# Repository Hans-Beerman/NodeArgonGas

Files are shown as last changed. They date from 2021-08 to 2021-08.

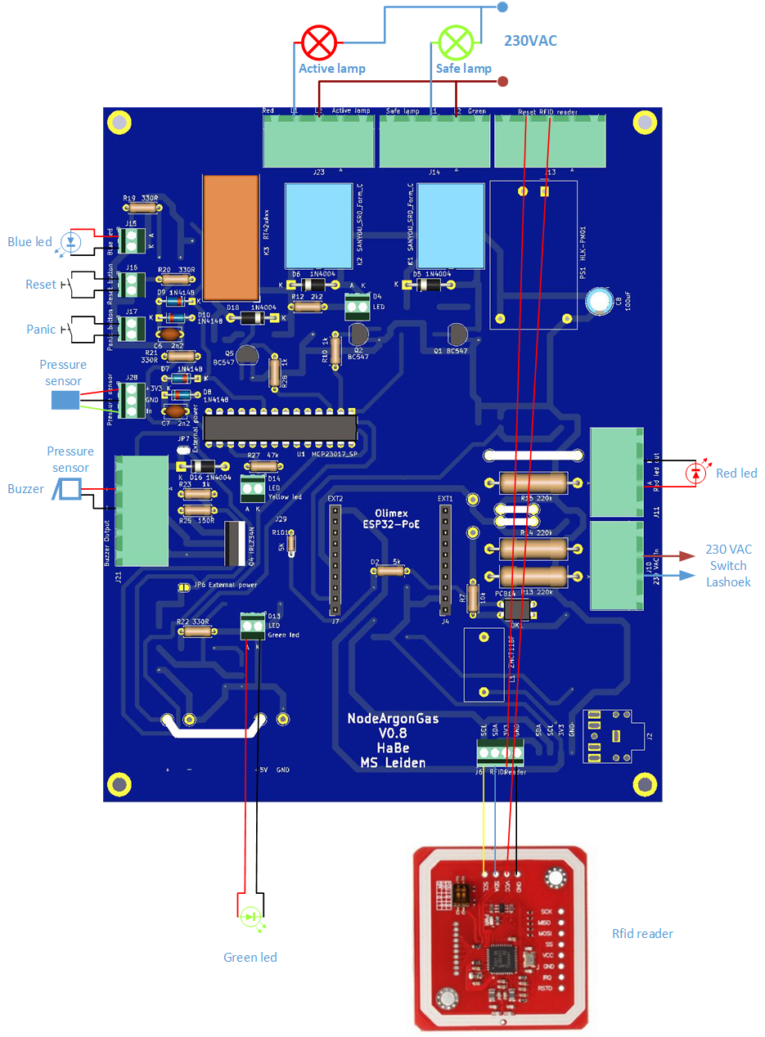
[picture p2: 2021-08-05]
Drawings/Aansluitschema PCB V0.1 20210801.png

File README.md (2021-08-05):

**NodeArgonGas**

NodeArgonGas is a node, used at the MakerSpace Leiden, to verify the state of the Argon Gas bottle, used for welding at the MakerSpace.

See for more information about this node:

[https://wiki.makerspaceleiden.nl/mediawiki/index.php/Project\_Monitoring\_Gasflessen](https://wiki.makerspaceleiden.nl/mediawiki/index.php/Project_Monitoring_Gasflessen)

This repository has the following subdirs:

**Drawings:**

- A schematic drawing, showing the wiring between the PCB used for this node and the external components, like push buttons, the pressure sensor, the RFid reader etc. (in MS Visio, png and pdf format);
- A \*.jpg picture of the PCB;
- Specification of the box in which the PCB and the other components are installed;
- A state diagram of software for this node (in MS Visio and pdf format).

**KiCad\_files:**

The design of the PCB used for the Node/Controller. For this node the NodeStandard PCB V0.8 is used. With less and other components than described for the NodeStandard. The changes are given in the MS Excel file in the root of this directory. There are also 2 subdirectories:

- _NodeArgonGas:_ This directory contains the schematic drawing for the NodeArgonGas and the PCB as used for this node. The design of the PCB in this directory is only made to show how the components for the node are placed on the NodeStandard PCB.
- _NodeStandard:_ This directory contains the design of the NodeStandard V0.8.

**Photos:**

Some photos of the Node made.

**PlatformIO\_Files:**

The source code for the Node. For the development of this software PlatformIO is used, an Extension on Visual Studio Code.

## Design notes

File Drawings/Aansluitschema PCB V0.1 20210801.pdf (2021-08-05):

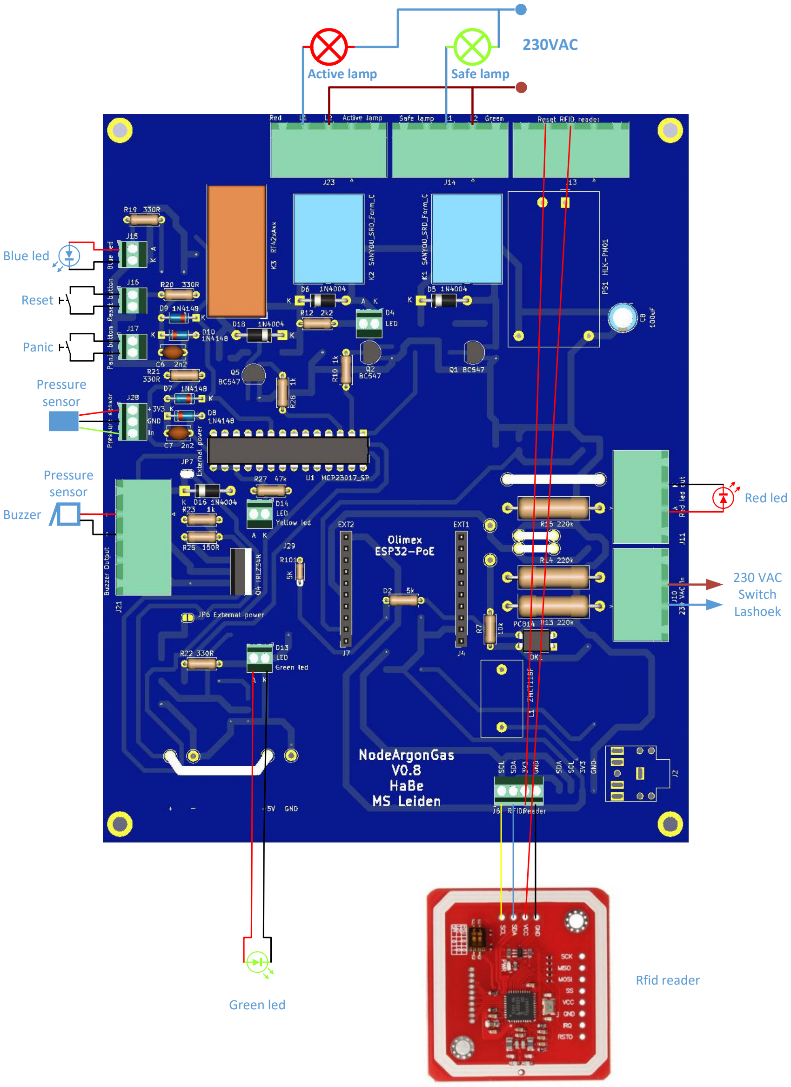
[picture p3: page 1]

Active lamp | Safe lamp

### 230VAC

Blue led

Reset

Panic

Buzzer

Pressure
sensor

Red led

Pressure
sensor

230 VAC
Switch
Lashoek

Rfid reader
Green led

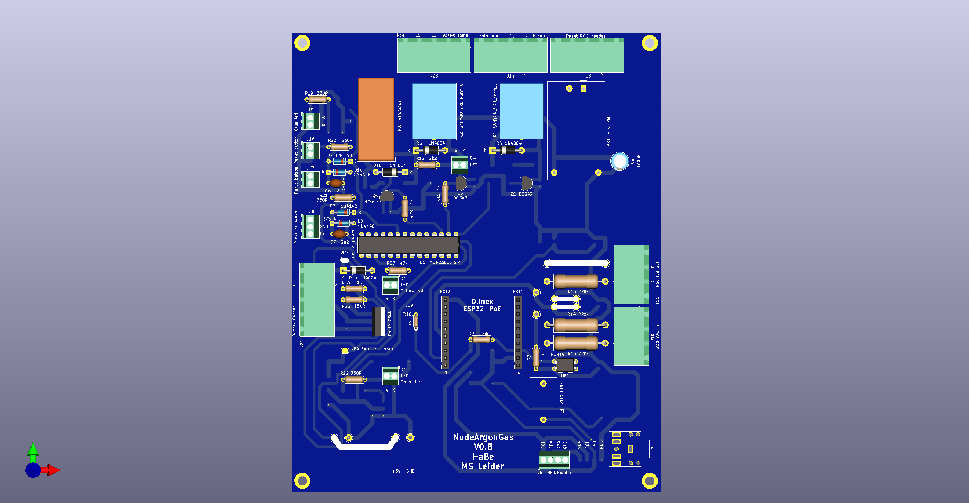
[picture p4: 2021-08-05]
KiCad_files/NodeArgonGas/NodeArgonGas.png

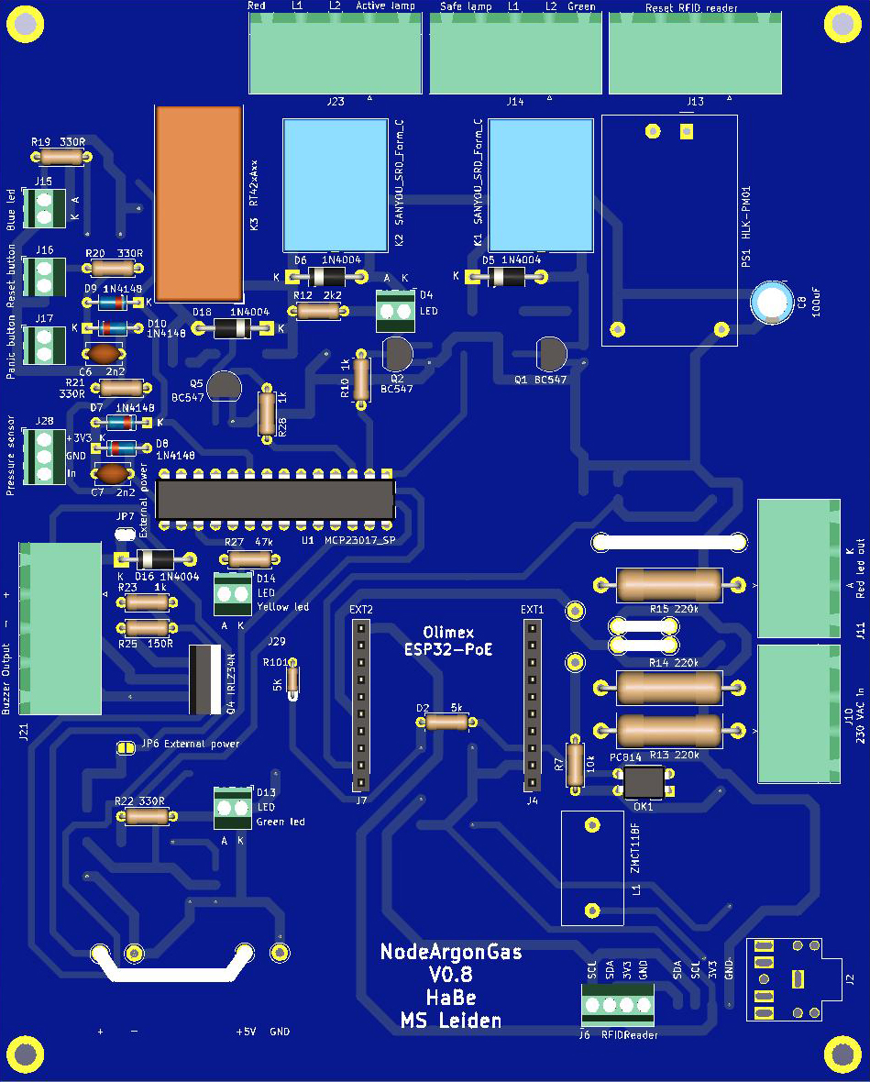
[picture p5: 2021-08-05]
Drawings/NodeArgonGas.jpg

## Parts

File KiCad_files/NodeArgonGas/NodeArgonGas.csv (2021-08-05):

Source: | /root/Projects/NodeArgonGas/KiCad_files/NodeArgonGas/NodeArgonGas.sch
Date: | ma 02 aug 2021 12:42:35 CEST
Tool: | Eeschema 5.1.10-88a1d61d58~90~ubuntu20.04.1
Generator: | /usr/share/kicad/plugins/bom_csv_grouped_by_value.py
Component Count: | 65
Individual Components:
Item | Qty | Reference(s) | Value | LibPart | Footprint | Datasheet | Field4 | Field5
 |  | C6 | 2n2 | Device:C | Capacitor_THT:C_Disc_D5.1mm_W3.2mm_P5.00mm | ~
 |  | C7 | 2n2 | Device:C | Capacitor_THT:C_Disc_D5.1mm_W3.2mm_P5.00mm | ~
 |  | C8 | 100uF | Device:CP | Capacitor_THT:CP_Radial_D6.3mm_P2.50mm | ~
 |  | D2 | 5k | Device:R | Resistor_THT:R_Axial_DIN0207_L6.3mm_D2.5mm_P7.62mm_Horizontal | ~
 |  | D4 | Led | Connector:Screw_Terminal_01x02 | Connector_Phoenix_MSTB:PhoenixContact_MSTB_2,5_2-GF-5,08_1x02_P5.08mm_Horizontal_ThreadedFlange | ~
 |  | D5 | 1N4004 | Diode:1N4004 | Diode_THT:D_DO-41_SOD81_P10.16mm_Horizontal | http://www.vishay.com/docs/88503/1n4001.pdf
 |  | D6 | 1N4004 | Diode:1N4004 | Diode_THT:D_DO-41_SOD81_P10.16mm_Horizontal | http://www.vishay.com/docs/88503/1n4001.pdf
 |  | D7 | 1N4148 | Diode:1N4148 | Diode_THT:D_DO-35_SOD27_P7.62mm_Horizontal | https://assets.nexperia.com/documents/data-sheet/1N4148_1N4448.pdf
 |  | D8 | 1N4148 | Diode:1N4148 | Diode_THT:D_DO-35_SOD27_P7.62mm_Horizontal | https://assets.nexperia.com/documents/data-sheet/1N4148_1N4448.pdf
 |  | D9 | 1N4148 | Diode:1N4148 | Diode_THT:D_DO-35_SOD27_P7.62mm_Horizontal | https://assets.nexperia.com/documents/data-sheet/1N4148_1N4448.pdf
 |  | D10 | 1N4148 | Diode:1N4148 | Diode_THT:D_DO-35_SOD27_P7.62mm_Horizontal | https://assets.nexperia.com/documents/data-sheet/1N4148_1N4448.pdf
 |  | D13 | Green led | Connector:Screw_Terminal_01x02 | Connector_Phoenix_MSTB:PhoenixContact_MSTB_2,5_2-GF-5,08_1x02_P5.08mm_Horizontal_ThreadedFlange | ~
 |  | D14 | Yellow led | Connector:Screw_Terminal_01x02 | Connector_Phoenix_MSTB:PhoenixContact_MSTB_2,5_2-GF-5,08_1x02_P5.08mm_Horizontal_ThreadedFlange | ~
 |  | D16 | 1N4004 | Diode:1N4004 | Diode_THT:D_DO-41_SOD81_P10.16mm_Horizontal | http://www.vishay.com/docs/88503/1n4001.pdf
 |  | D18 | 1N4004 | Diode:1N4004 | Diode_THT:D_DO-41_SOD81_P10.16mm_Horizontal | http://www.vishay.com/docs/88503/1n4001.pdf
 |  | J4 | EXT1 | Connector_Generic:Conn_01x10 | Connector_PinSocket_2.54mm:PinSocket_1x10_P2.54mm_Vertical | ~
 |  | J6 | RFIDReader | Connector:Screw_Terminal_01x04 | TerminalBlock_Phoenix:TerminalBlock_Phoenix_MPT-0,5-4-2.54_1x04_P2.54mm_Horizontal | ~
 |  | J7 | EXT2 | Connector_Generic:Conn_01x10 | Connector_PinSocket_2.54mm:PinSocket_1x10_P2.54mm_Vertical | ~
 |  | J10 | Opto Coupler 1 in | Connector:Screw_Terminal_01x02 | Connector_Phoenix_MSTB:PhoenixContact_MSTB_2,5_2-GF-5,08_1x02_P5.08mm_Horizontal_ThreadedFlange | ~
 |  | J11 | Red led output | Connector:Screw_Terminal_01x02 | Connector_Phoenix_MSTB:PhoenixContact_MSTB_2,5_2-GF-5,08_1x02_P5.08mm_Horizontal_ThreadedFlange | ~
 |  | J13 | Reset RFid reader | Connector:Screw_Terminal_01x03 | Connector_Phoenix_MSTB:PhoenixContact_MSTB_2,5_3-GF-5,08_1x03_P5.08mm_Horizontal_ThreadedFlange | ~
 |  | J14 | Safe lamp (Output) | Connector:Screw_Terminal_01x03 | Connector_Phoenix_MSTB:PhoenixContact_MSTB_2,5_3-GF-5,08_1x03_P5.08mm_Horizontal_ThreadedFlange | ~
 |  | J15 | Blue led out | Connector:Screw_Terminal_01x02 | TerminalBlock_Phoenix:TerminalBlock_Phoenix_MPT-0,5-2-2.54_1x02_P2.54mm_Horizontal | ~
 |  | J16 | Panic button in | Connector:Screw_Terminal_01x02 | TerminalBlock_Phoenix:TerminalBlock_Phoenix_MPT-0,5-2-2.54_1x02_P2.54mm_Horizontal | ~
 |  | J17 | Reset button in | Connector:Screw_Terminal_01x02 | TerminalBlock_Phoenix:TerminalBlock_Phoenix_MPT-0,5-2-2.54_1x02_P2.54mm_Horizontal | ~
 |  | J21 | Buzzer output | Connector:Screw_Terminal_01x03 | Connector_Phoenix_MSTB:PhoenixContact_MSTB_2,5_3-GF-5,08_1x03_P5.08mm_Horizontal_ThreadedFlange | ~
 |  | J23 | Active lamp (output) | Connector:Screw_Terminal_01x03 | Connector_Phoenix_MSTB:PhoenixContact_MSTB_2,5_3-GF-5,08_1x03_P5.08mm_Horizontal_ThreadedFlange | ~
 |  | J24 | Relay 3 Output 2 (not installed) | Connector:Screw_Terminal_01x03 | Connector_Phoenix_MSTB:PhoenixContact_MSTB_2,5_3-GF-5,08_1x03_P5.08mm_Horizontal_ThreadedFlange | ~
 |  | J25 | 230VAC in | Connector:Screw_Terminal_01x02 | Connector_Phoenix_MSTB:PhoenixContact_MSTB_2,5_2-GF-5,08_1x02_P5.08mm_Horizontal_ThreadedFlange | ~
 |  | J26 | 5V-in | Connector:Screw_Terminal_01x02 | Connector_Phoenix_MSTB:PhoenixContact_MSTB_2,5_2-GF-5,08_1x02_P5.08mm_Horizontal_ThreadedFlange | ~
 |  | J27 | ExtDC-in | Connector:Screw_Terminal_01x02 | Connector_Phoenix_MSTB:PhoenixContact_MSTB_2,5_2-GF-5,08_1x02_P5.08mm_Horizontal_ThreadedFlange | ~
 |  | J28 | Pressure sensor | Connector:Screw_Terminal_01x03 | TerminalBlock_Phoenix:TerminalBlock_Phoenix_MPT-0,5-3-2.54_1x03_P2.54mm_Horizontal | ~
 |  | J29 | J29 is replaced by R101 | Connector_Generic:Conn_01x03 | Connector_PinHeader_2.54mm:PinHeader_1x03_P2.54mm_Vertical | ~
 |  | JP1 | 230VAC-N | Jumper:SolderJumper_2_Open | Footprints:SolderJumper-2_P3mm_Open_RoundedPad | ~
 |  | JP4 | 230VAC-L | Jumper:SolderJumper_2_Open | Footprints:SolderJumper-2_P3mm_Open_RoundedPad | ~
 |  | JP5 | 230VAC-L | Jumper:SolderJumper_2_Open | Footprints:SolderJumper-2_P3mm_Open_RoundedPad | ~
 |  | JP7 | External power | Jumper:SolderJumper_2_Open | Jumper:SolderJumper-2_P1.3mm_Open_RoundedPad1.0x1.5mm | ~
 |  | JP8 | 230VAC-L | Jumper:SolderJumper_2_Open | Footprints:SolderJumper-2_P3mm_Open_RoundedPad | ~
 |  | K1 | SANYOU_SRD_Form_C | Relay:SANYOU_SRD_Form_C | Relay_THT:Relay_SPDT_SANYOU_SRD_Series_Form_C | http://www.sanyourelay.ca/public/products/pdf/SRD.pdf
 |  | K2 | SANYOU_SRD_Form_C | Relay:SANYOU_SRD_Form_C | Relay_THT:Relay_SPDT_SANYOU_SRD_Series_Form_C | http://www.sanyourelay.ca/public/products/pdf/SRD.pdf
 |  | K3 | RT42xAxx | Relay:RT42xAxx | Relay_THT:Relay_DPDT_Schrack-RT2-FormC_RM5mm | http://www.te.com/commerce/DocumentDelivery/DDEController?Action=showdoc
 |  | OK1 | PC814 | PC814:PC814 | Package_DIP:DIP-4_W7.62mm |  | unknown | 9707662
 |  | PS1 | HLK-PM01 | Converter_ACDC:HLK-PM01 | Converter_ACDC:Converter_ACDC_HiLink_HLK-PMxx | http://www.hlktech.net/product_detail.php?ProId=54
 |  | Q1 | BC547 | Transistor_BJT:BC547 | Package_TO_SOT_THT:TO-92_Inline | http://www.fairchildsemi.com/ds/BC/BC547.pdf
 |  | Q2 | BC547 | Transistor_BJT:BC547 | Package_TO_SOT_THT:TO-92_Inline | http://www.fairchildsemi.com/ds/BC/BC547.pdf
 |  | Q4 | IRLZ34N | Transistor_FET:IRLZ34N | Package_TO_SOT_THT:TO-220-3_Vertical | http://www.infineon.com/dgdl/irlz34npbf.pdf?fileId=5546d462533600a40153567206892720
 |  | Q5 | BC547 | Transistor_BJT:BC547 | Package_TO_SOT_THT:TO-92_Inline | http://www.fairchildsemi.com/ds/BC/BC547.pdf
 |  | R7 | 10k | Device:R | Resistor_THT:R_Axial_DIN0207_L6.3mm_D2.5mm_P7.62mm_Horizontal | ~
 |  | R9 | 1k | Device:R | Resistor_THT:R_Axial_DIN0207_L6.3mm_D2.5mm_P7.62mm_Horizontal | ~
 |  | R10 | 1k | Device:R | Resistor_THT:R_Axial_DIN0207_L6.3mm_D2.5mm_P7.62mm_Horizontal | ~
 |  | R12 | 2k2 | Device:R | Resistor_THT:R_Axial_DIN0207_L6.3mm_D2.5mm_P7.62mm_Horizontal | ~
 |  | R13 | 220k | Device:R | Resistor_THT:R_Axial_DIN0516_L15.5mm_D5.0mm_P20.32mm_Horizontal | ~
 |  | R14 | 220k | Device:R | Resistor_THT:R_Axial_DIN0516_L15.5mm_D5.0mm_P20.32mm_Horizontal | ~
 |  | R15 | 330R | Device:R | Resistor_THT:R_Axial_DIN0516_L15.5mm_D5.0mm_P20.32mm_Horizontal | ~
 |  | R16 | 0R | Device:R | Resistor_THT:R_Axial_DIN0516_L15.5mm_D5.0mm_P20.32mm_Horizontal | ~
 |  | R19 | 330R | Device:R | Resistor_THT:R_Axial_DIN0207_L6.3mm_D2.5mm_P7.62mm_Horizontal | ~
 |  | R20 | 330R | Device:R | Resistor_THT:R_Axial_DIN0207_L6.3mm_D2.5mm_P7.62mm_Horizontal | ~
 |  | R21 | 330R | Device:R | Resistor_THT:R_Axial_DIN0207_L6.3mm_D2.5mm_P7.62mm_Horizontal | ~
 |  | R22 | 330R | Device:R | Resistor_THT:R_Axial_DIN0207_L6.3mm_D2.5mm_P7.62mm_Horizontal | ~
 |  | R23 | 1k | Device:R | Resistor_THT:R_Axial_DIN0207_L6.3mm_D2.5mm_P7.62mm_Horizontal | ~
 |  | R25 | 150R | Device:R | Resistor_THT:R_Axial_DIN0207_L6.3mm_D2.5mm_P7.62mm_Horizontal | ~
 |  | R27 | 47k | Device:R | Resistor_THT:R_Axial_DIN0207_L6.3mm_D2.5mm_P7.62mm_Horizontal | ~
 |  | R28 | 1k | Device:R | Resistor_THT:R_Axial_DIN0207_L6.3mm_D2.5mm_P7.62mm_Horizontal | ~
 |  | R101 | 5k | Device:R | Resistor_THT:R_Axial_DIN0207_L6.3mm_D2.5mm_P7.62mm_Horizontal | ~
 |  | U1 | MCP23017_SP | Interface_Expansion:MCP23017_SP | Package_DIP:DIP-28_W7.62mm | http://ww1.microchip.com/downloads/en/DeviceDoc/20001952C.pdf
Collated Components:
Item | Qty | Reference(s) | Value | LibPart | Footprint | Datasheet | Field4 | Field5
1 | 2 | C6, C7 | 2n2 | Device:C | Capacitor_THT:C_Disc_D5.1mm_W3.2mm_P5.00mm | ~
2 | 1 | C8 | 100uF | Device:CP | Capacitor_THT:CP_Radial_D6.3mm_P2.50mm | ~
3 | 2 | D2, R101 | 5k | Device:R | Resistor_THT:R_Axial_DIN0207_L6.3mm_D2.5mm_P7.62mm_Horizontal | ~
4 | 1 | D4 | Led | Connector:Screw_Terminal_01x02 | Connector_Phoenix_MSTB:PhoenixContact_MSTB_2,5_2-GF-5,08_1x02_P5.08mm_Horizontal_ThreadedFlange | ~
5 | 4 | D5, D6, D16, D18 | 1N4004 | Diode:1N4004 | Diode_THT:D_DO-41_SOD81_P10.16mm_Horizontal | http://www.vishay.com/docs/88503/1n4001.pdf
6 | 4 | D7, D8, D9, D10 | 1N4148 | Diode:1N4148 | Diode_THT:D_DO-35_SOD27_P7.62mm_Horizontal | https://assets.nexperia.com/documents/data-sheet/1N4148_1N4448.pdf
7 | 1 | D13 | Green led | Connector:Screw_Terminal_01x02 | Connector_Phoenix_MSTB:PhoenixContact_MSTB_2,5_2-GF-5,08_1x02_P5.08mm_Horizontal_ThreadedFlange | ~
8 | 1 | D14 | Yellow led | Connector:Screw_Terminal_01x02 | Connector_Phoenix_MSTB:PhoenixContact_MSTB_2,5_2-GF-5,08_1x02_P5.08mm_Horizontal_ThreadedFlange | ~
9 | 1 | J4 | EXT1 | Connector_Generic:Conn_01x10 | Connector_PinSocket_2.54mm:PinSocket_1x10_P2.54mm_Vertical | ~
10 | 1 | J6 | RFIDReader | Connector:Screw_Terminal_01x04 | TerminalBlock_Phoenix:TerminalBlock_Phoenix_MPT-0,5-4-2.54_1x04_P2.54mm_Horizontal | ~
11 | 1 | J7 | EXT2 | Connector_Generic:Conn_01x10 | Connector_PinSocket_2.54mm:PinSocket_1x10_P2.54mm_Vertical | ~
12 | 1 | J10 | Opto Coupler 1 in | Connector:Screw_Terminal_01x02 | Connector_Phoenix_MSTB:PhoenixContact_MSTB_2,5_2-GF-5,08_1x02_P5.08mm_Horizontal_ThreadedFlange | ~
13 | 1 | J11 | Red led output | Connector:Screw_Terminal_01x02 | Connector_Phoenix_MSTB:PhoenixContact_MSTB_2,5_2-GF-5,08_1x02_P5.08mm_Horizontal_ThreadedFlange | ~
14 | 1 | J13 | Reset RFid reader | Connector:Screw_Terminal_01x03 | Connector_Phoenix_MSTB:PhoenixContact_MSTB_2,5_3-GF-5,08_1x03_P5.08mm_Horizontal_ThreadedFlange | ~
15 | 1 | J14 | Safe lamp (Output) | Connector:Screw_Terminal_01x03 | Connector_Phoenix_MSTB:PhoenixContact_MSTB_2,5_3-GF-5,08_1x03_P5.08mm_Horizontal_ThreadedFlange | ~
16 | 1 | J15 | Blue led out | Connector:Screw_Terminal_01x02 | TerminalBlock_Phoenix:TerminalBlock_Phoenix_MPT-0,5-2-2.54_1x02_P2.54mm_Horizontal | ~
17 | 1 | J16 | Panic button in | Connector:Screw_Terminal_01x02 | TerminalBlock_Phoenix:TerminalBlock_Phoenix_MPT-0,5-2-2.54_1x02_P2.54mm_Horizontal | ~
18 | 1 | J17 | Reset button in | Connector:Screw_Terminal_01x02 | TerminalBlock_Phoenix:TerminalBlock_Phoenix_MPT-0,5-2-2.54_1x02_P2.54mm_Horizontal | ~
19 | 1 | J21 | Buzzer output | Connector:Screw_Terminal_01x03 | Connector_Phoenix_MSTB:PhoenixContact_MSTB_2,5_3-GF-5,08_1x03_P5.08mm_Horizontal_ThreadedFlange | ~
20 | 1 | J23 | Active lamp (output) | Connector:Screw_Terminal_01x03 | Connector_Phoenix_MSTB:PhoenixContact_MSTB_2,5_3-GF-5,08_1x03_P5.08mm_Horizontal_ThreadedFlange | ~
21 | 1 | J24 | Relay 3 Output 2 (not installed) | Connector:Screw_Terminal_01x03 | Connector_Phoenix_MSTB:PhoenixContact_MSTB_2,5_3-GF-5,08_1x03_P5.08mm_Horizontal_ThreadedFlange | ~
22 | 1 | J25 | 230VAC in | Connector:Screw_Terminal_01x02 | Connector_Phoenix_MSTB:PhoenixContact_MSTB_2,5_2-GF-5,08_1x02_P5.08mm_Horizontal_ThreadedFlange | ~
23 | 1 | J26 | 5V-in | Connector:Screw_Terminal_01x02 | Connector_Phoenix_MSTB:PhoenixContact_MSTB_2,5_2-GF-5,08_1x02_P5.08mm_Horizontal_ThreadedFlange | ~
24 | 1 | J27 | ExtDC-in | Connector:Screw_Terminal_01x02 | Connector_Phoenix_MSTB:PhoenixContact_MSTB_2,5_2-GF-5,08_1x02_P5.08mm_Horizontal_ThreadedFlange | ~
25 | 1 | J28 | Pressure sensor | Connector:Screw_Terminal_01x03 | TerminalBlock_Phoenix:TerminalBlock_Phoenix_MPT-0,5-3-2.54_1x03_P2.54mm_Horizontal | ~
26 | 1 | J29 | J29 is replaced by R101 | Connector_Generic:Conn_01x03 | Connector_PinHeader_2.54mm:PinHeader_1x03_P2.54mm_Vertical | ~
27 | 1 | JP1 | 230VAC-N | Jumper:SolderJumper_2_Open | Footprints:SolderJumper-2_P3mm_Open_RoundedPad | ~
28 | 3 | JP4, JP5, JP8 | 230VAC-L | Jumper:SolderJumper_2_Open | Footprints:SolderJumper-2_P3mm_Open_RoundedPad | ~
29 | 1 | JP7 | External power | Jumper:SolderJumper_2_Open | Jumper:SolderJumper-2_P1.3mm_Open_RoundedPad1.0x1.5mm | ~
30 | 2 | K1, K2 | SANYOU_SRD_Form_C | Relay:SANYOU_SRD_Form_C | Relay_THT:Relay_SPDT_SANYOU_SRD_Series_Form_C | http://www.sanyourelay.ca/public/products/pdf/SRD.pdf
31 | 1 | K3 | RT42xAxx | Relay:RT42xAxx | Relay_THT:Relay_DPDT_Schrack-RT2-FormC_RM5mm | http://www.te.com/commerce/DocumentDelivery/DDEController?Action=showdoc
32 | 1 | OK1 | PC814 | PC814:PC814 | Package_DIP:DIP-4_W7.62mm |  | unknown | 9707662
33 | 1 | PS1 | HLK-PM01 | Converter_ACDC:HLK-PM01 | Converter_ACDC:Converter_ACDC_HiLink_HLK-PMxx | http://www.hlktech.net/product_detail.php?ProId=54
34 | 3 | Q1, Q2, Q5 | BC547 | Transistor_BJT:BC547 | Package_TO_SOT_THT:TO-92_Inline | http://www.fairchildsemi.com/ds/BC/BC547.pdf
35 | 1 | Q4 | IRLZ34N | Transistor_FET:IRLZ34N | Package_TO_SOT_THT:TO-220-3_Vertical | http://www.infineon.com/dgdl/irlz34npbf.pdf?fileId=5546d462533600a40153567206892720
36 | 1 | R7 | 10k | Device:R | Resistor_THT:R_Axial_DIN0207_L6.3mm_D2.5mm_P7.62mm_Horizontal | ~
37 | 4 | R9, R10, R23, R28 | 1k | Device:R | Resistor_THT:R_Axial_DIN0207_L6.3mm_D2.5mm_P7.62mm_Horizontal | ~
38 | 1 | R12 | 2k2 | Device:R | Resistor_THT:R_Axial_DIN0207_L6.3mm_D2.5mm_P7.62mm_Horizontal | ~
39 | 2 | R13, R14 | 220k | Device:R | Resistor_THT:R_Axial_DIN0516_L15.5mm_D5.0mm_P20.32mm_Horizontal | ~
40 | 1 | R15 | 330R | Device:R | Resistor_THT:R_Axial_DIN0516_L15.5mm_D5.0mm_P20.32mm_Horizontal | ~
41 | 1 | R16 | 0R | Device:R | Resistor_THT:R_Axial_DIN0516_L15.5mm_D5.0mm_P20.32mm_Horizontal | ~
42 | 4 | R19, R20, R21, R22 | 330R | Device:R | Resistor_THT:R_Axial_DIN0207_L6.3mm_D2.5mm_P7.62mm_Horizontal | ~
43 | 1 | R25 | 150R | Device:R | Resistor_THT:R_Axial_DIN0207_L6.3mm_D2.5mm_P7.62mm_Horizontal | ~
44 | 1 | R27 | 47k | Device:R | Resistor_THT:R_Axial_DIN0207_L6.3mm_D2.5mm_P7.62mm_Horizontal | ~
45 | 1 | U1 | MCP23017_SP | Interface_Expansion:MCP23017_SP | Package_DIP:DIP-28_W7.62mm | http://ww1.microchip.com/downloads/en/DeviceDoc/20001952C.pdf

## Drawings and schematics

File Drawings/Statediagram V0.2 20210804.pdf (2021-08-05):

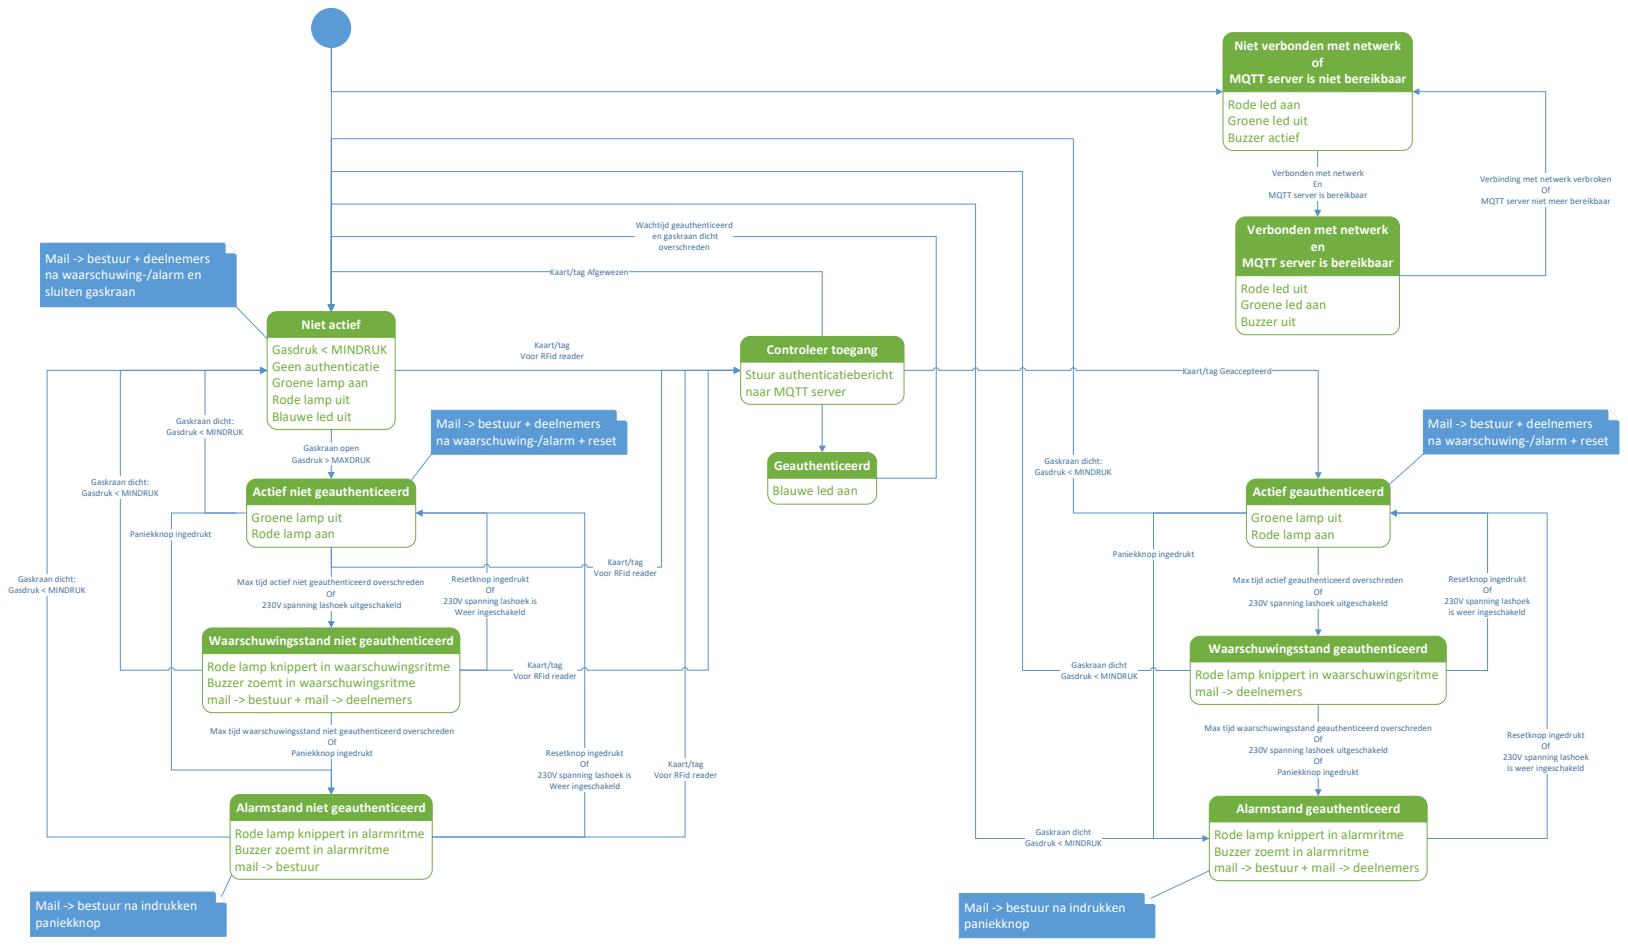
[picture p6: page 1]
Kaart/tag; Voor RFid reader; Controleer toegang; Of Paniekknop ingedrukt; Gaskraan dicht Gasdruk < MINDRUK; Gaskraan dicht: Gasdruk < MINDRUK; Resetknop ingedrukt Of; Paniekknop ingedrukt

Niet verbonden met netwerk

MQTT server is niet bereikbaar
Rode led aan
Groene led uit
Buzzer actief

Verbonden met netwerk MQTT server is bereikbaar | En

Verbinding met netwerk verbroken MQTT server niet meer bereikbaar | Of

Wachtijd geauthenticeerd
en gaskraan dicht
overschreden

Verbonden met netwerk

Mail -> bestuur + deelnemers
na waarschuwing-/alarm en
sluiten gaskraan

MQTT server is bereikbaar
Rode led uit
Groene led aan
Buzzer uit

Kaart/tag Afgewezen

Niet actief
Gasdruk < MINDRUK
Geen authenticatie
Groene lamp aan
Rode lamp uit
Blauwe led uit

Stuur authenticatiebericht
naar MQTT server

Kaart/tag Geaccepteerd

Gaskraan dicht: Gasdruk < MINDRUK

na waarschuwing-/alarm + reset

Gaskraan open Gasdruk > MAXDRUK

Geauthenticeerd
Blauwe led aan

Actief niet geauthenticeerd
Groene lamp uit
Rode lamp aan

Actief geauthenticeerd

Kaart/tag
Voor RFid reader

Max tijd actief niet geauthenticeerd overschreden

Max tijd actief geauthenticeerd overschreden

230V spanning lashoek uitgeschakeld

230V spanning lashoek is
Weer ingeschakeld

230V spanning lashoek
is weer ingeschakeld

Waarschuwingsstand niet geauthenticeerd
Rode lamp knippert in waarschuwingsritme
Buzzer zoemt in waarschuwingsritme
mail -> bestuur + mail -> deelnemers

Waarschuwingsstand geauthenticeerd
mail -> deelnemers

Max tijd waarschuwingsstand niet geauthenticeerd overschreden

Max tijd waarschuwingsstand geauthenticeerd overschreden

Is weer ingeschakeld

Alarmstand niet geauthenticeerd
Rode lamp knippert in alarmritme
Buzzer zoemt in alarmritme
mail -> bestuur

Alarmstand geauthenticeerd

Mail -> bestuur na indrukken
paniekknop

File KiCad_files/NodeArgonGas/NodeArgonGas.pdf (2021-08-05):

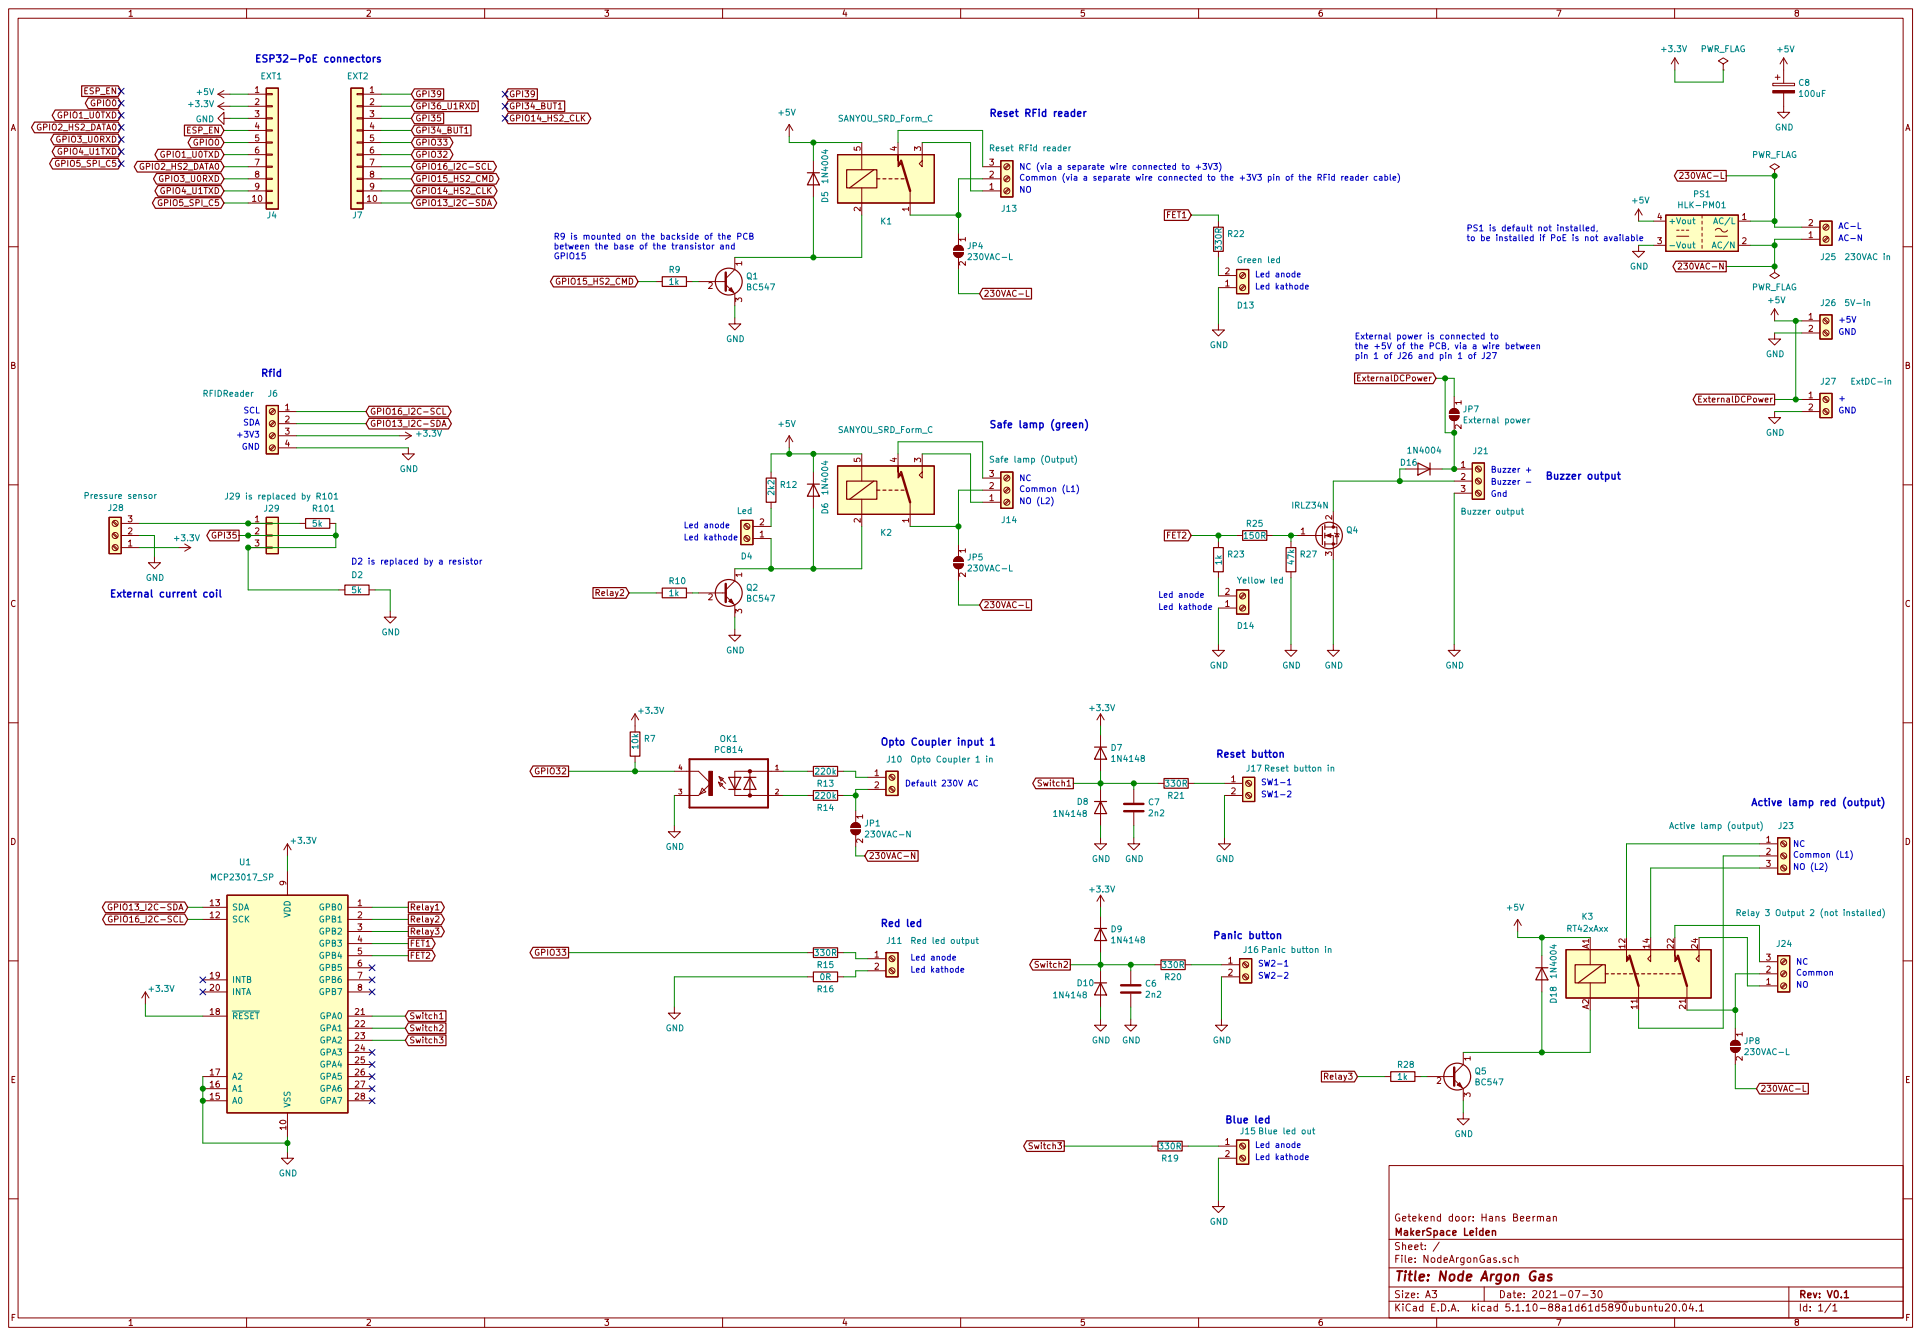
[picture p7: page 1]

pin 1 of J26 and pin 1 of J27 ESP32-PoE connectors

NC (via a separate wire connected to +3V3)
Common (via a separate wire connected to the +3V3 pin of the RFid reader cable)

to be installed if PoE is not available

External power is connected to
the +5V of the PCB, via a wire between

Led kathode D2 is replaced by a resistor

NC Active lamp red (output)

Panic button Blue led

J24 Relay 3 Output 2 (not installed)

File: NodeArgonGas.sch Sheet: / MakerSpace Leiden Getekend door: Hans Beerman

Id: 1/1 Title: Node Argon Gas

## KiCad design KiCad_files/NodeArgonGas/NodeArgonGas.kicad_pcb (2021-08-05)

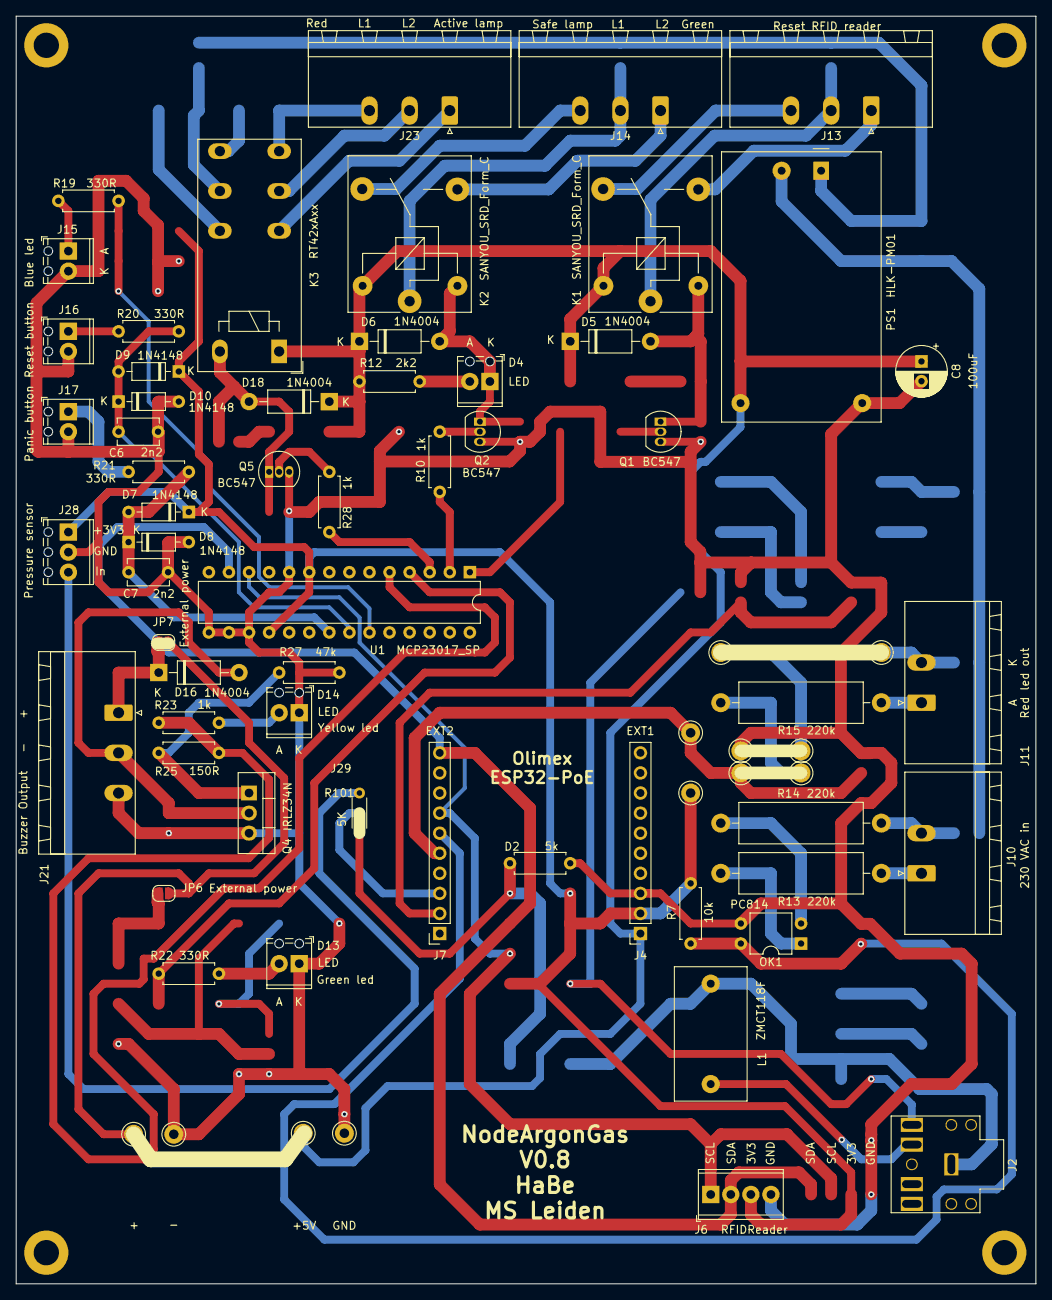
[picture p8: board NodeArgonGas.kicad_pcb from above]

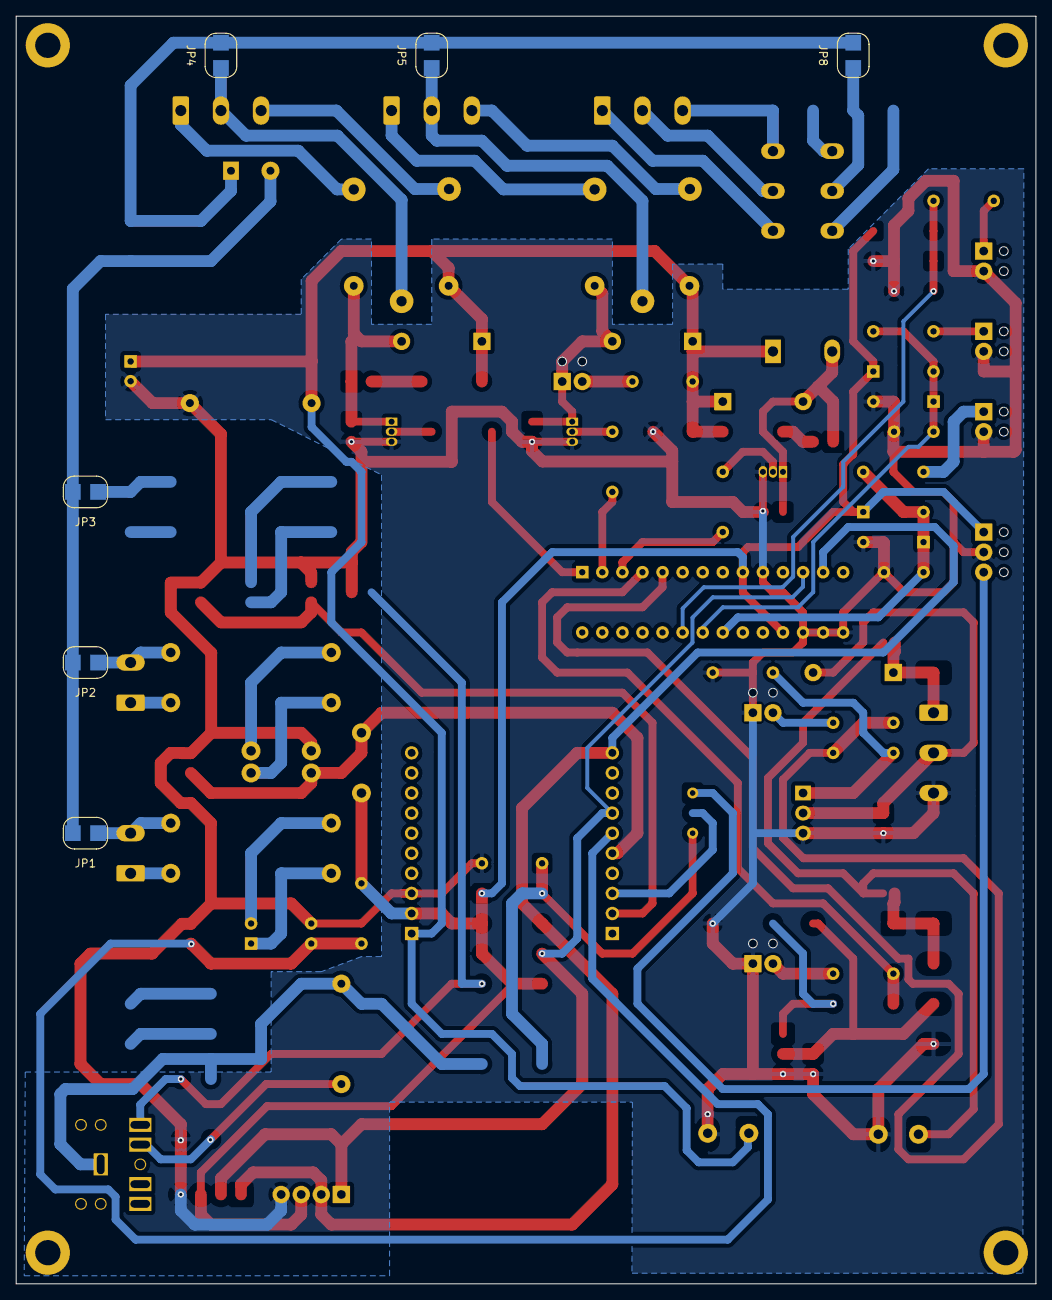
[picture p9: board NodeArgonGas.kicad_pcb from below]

Board: 2 copper layers, 129.0 x 160.4 mm, 63 parts (6 on the bottom side), 50 nets.

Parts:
C6, C7: 2n2; C_Disc_D5.1mm_W3.2mm_P5.00mm
C8: 100uF; CP_Radial_D6.3mm_P2.50mm
D2: 5k; R_Axial_DIN0207_L6.3mm_D2.5mm_P7.62mm_Horizontal
D4, D13, D14: LED; TerminalBlock_Phoenix_MPT-0,5-2-2.54_1x02_P2.54mm_Horizontal
D5, D6, D16, D18: 1N4004; D_DO-41_SOD81_P10.16mm_Horizontal
D7, D8, D9, D10: 1N4148; D_DO-35_SOD27_P7.62mm_Horizontal
J2: Current coil in; Jack_3.5mm_CUI_FEMPM_Horizontal
J4: EXT1; PinSocket_1x10_P2.54mm_Vertical
J6: RFIDReader; TerminalBlock_Phoenix_MPT-0,5-4-2.54_1x04_P2.54mm_Horizontal
J7: EXT2; PinSocket_1x10_P2.54mm_Vertical
J10: 230 VAC in; PhoenixContact_MSTB_2,5_2-GF-5,08_1x02_P5.08mm_Horizontal_T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
J11: Red led out; PhoenixContact_MSTB_2,5_2-GF-5,08_1x02_P5.08mm_Horizontal_T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
J13: Reset RFID reader; PhoenixContact_MSTB_2,5_3-GF-5,08_1x03_P5.08mm_Horizontal_T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
J14: Safe lamp L1 L2 Green; PhoenixContact_MSTB_2,5_3-GF-5,08_1x03_P5.08mm_Horizontal_T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
J15: Blue led; TerminalBlock_Phoenix_MPT-0,5-2-2.54_1x02_P2.54mm_Horizontal
J16: Reset button; TerminalBlock_Phoenix_MPT-0,5-2-2.54_1x02_P2.54mm_Horizontal
J17: Panic button; TerminalBlock_Phoenix_MPT-0,5-2-2.54_1x02_P2.54mm_Horizontal
J21: Buzzer Output - +; PhoenixContact_MSTB_2,5_3-GF-5,08_1x03_P5.08mm_Horizontal_T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
J23: Red L1 L2 Active lamp; PhoenixContact_MSTB_2,5_3-GF-5,08_1x03_P5.08mm_Horizontal_T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
J28: Pressure sensor; TerminalBlock_Phoenix_MPT-0,5-3-2.54_1x03_P2.54mm_Horizontal
J29: 5K; R_Axial_DIN0204_L3.6mm_D1.6mm_P5.08mm_Horizontal
JP1, JP2, JP3: 230VAC-N; SolderJumper-2_P3mm_Open_RoundedPad
JP4, JP5, JP8: 230VAC-L; SolderJumper-2_P3mm_Open_RoundedPad
JP6, JP7: External power; SolderJumper-2_P1.3mm_Open_RoundedPad1.0x1.5mm
K1, K2: SANYOU_SRD_Form_C; Relay_SPDT_SANYOU_SRD_Series_Form_C
K3: RT42xAxx; Relay_DPDT_Schrack-RT2-FormC_RM5mm
L1: ZMCT118F; TA12-100
OK1: PC814; DIP-4_W7.62mm
PS1: HLK-PM01; Converter_ACDC_HiLink_HLK-PMxx
Q1, Q2, Q5: BC547; TO-92_Inline
Q4: IRLZ34N; TO-220-3_Vertical
R7: 10k; R_Axial_DIN0207_L6.3mm_D2.5mm_P7.62mm_Horizontal
R10, R23, R28: 1k; R_Axial_DIN0207_L6.3mm_D2.5mm_P7.62mm_Horizontal
R12: 2k2; R_Axial_DIN0207_L6.3mm_D2.5mm_P7.62mm_Horizontal
R13, R14, R15: 220k; R_Axial_DIN0516_L15.5mm_D5.0mm_P20.32mm_Horizontal
R19, R20, R21, R22: 330R; R_Axial_DIN0207_L6.3mm_D2.5mm_P7.62mm_Horizontal
R25: 150R; R_Axial_DIN0207_L6.3mm_D2.5mm_P7.62mm_Horizontal
R27: 47k; R_Axial_DIN0207_L6.3mm_D2.5mm_P7.62mm_Horizontal
U1: MCP23017_SP; DIP-28_W7.62mm

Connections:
230VAC-L: JP4.2, JP5.2, JP8.2, PS1.1
230VAC-N: JP1.2, JP2.2, JP3.2, PS1.2
+3V3: D7.1, D9.1, J4.2, J6.3, J28.1, R7.1, U1.9, U1.18
+5V: C8.1, D5.1, D6.1, D18.1, J4.1, K1.5, K2.5, K3.A1, PS1.4, R12.1
ExternalDCPower: JP6.1, JP7.1
FET1: R22.1, U1.4
FET2: R23.1, R25.2, U1.5
GND: C6.2, C7.2, C8.2, D2.2, D8.2, D10.2, D13.1, D14.1, J4.3, J6.4, J15.2, J16.2, J17.2, J28.2, OK1.3, PS1.3, Q1.3, Q2.3, Q4.3, Q5.3, R27.2, U1.10, U1.15, U1.16, U1.17
GPI35: J7.3, J29.2
GPIO13_I2C-SDA: J6.2, J7.10, U1.13
GPIO16_I2C-SCL: J6.1, J7.7, U1.12
GPIO32: J7.6, OK1.4, R7.2
unnamed: D5.2, K1.2, Q1.1
unnamed: D4.1, D6.2, K2.2, Q2.1
unnamed: D4.2, R12.2
unnamed: D13.2, R22.2
unnamed: D14.2, R23.2
unnamed: D16.1, J21.1, J21.2, JP7.2
unnamed: D16.2, J21.3, Q4.2
unnamed: D18.2, K3.A2, Q5.1
unnamed: J2.S, L1.2
unnamed: J2.TN, L1.1
unnamed: J10.1, R13.1
unnamed: J10.2, JP1.1, R14.1
unnamed: J11.1, R15.1
unnamed: J11.2, JP2.1
unnamed: J13.1, K1.3
unnamed: J13.2, JP4.1, K1.1
unnamed: J13.3, K1.4
unnamed: J14.1, K2.3
unnamed: J14.2, JP5.1, K2.1
unnamed: J14.3, K2.4
unnamed: J15.1, R19.1
unnamed: J16.1, R20.1
unnamed: J17.1, R21.1
unnamed: J23.1, K3.12
unnamed: J23.2, K3.11
unnamed: J23.3, K3.14
unnamed: JP8.1, K3.21
unnamed: J28.3, J29.1
unnamed: OK1.1, R13.2
unnamed: OK1.2, R14.2
unnamed: Q2.2, R10.1
unnamed: Q4.1, R25.1, R27.1
unnamed: Q5.2, R28.1
Relay2: R10.2, U1.2
Relay3: R28.2, U1.3
Switch1: C7.1, D7.2, D8.1, R21.2, U1.21
Switch2: C6.1, D9.2, D10.1, R20.2, U1.22
Switch3: R19.2, U1.23

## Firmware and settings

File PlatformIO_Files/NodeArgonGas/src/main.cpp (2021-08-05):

/*
   Copyright 2015-2018 Dirk-Willem van Gulik <dirkx@webweaving.org>
   Copyright 2020-2021 Hans Beerman <hans.beerman@xs4all.nl>
                       Stichting Makerspace Leiden, the Netherlands.

   Licensed under the Apache License, Version 2.0 (the "License");
   you may not use this file except in compliance with the License.
   You may obtain a copy of the License at

       http://www.apache.org/licenses/LICENSE-2.0

   Unless required by applicable law or agreed to in writing, software
   distributed under the License is distributed on an "AS IS" BASIS,
   WITHOUT WARRANTIES OR CONDITIONS OF ANY KIND, either express or implied.
   See the License for the specific language governing permissions and
   limitations under the License.
*/

#ifndef ESP32
#error "The NodeArgonGase uses an ESP32 based board (Olimex ESP32-PoE)!"
#endif

// An Olimex ESP32-PoE is used (default is POESP board (Aart board))
#define ESP32_PoE


// for debugging
// see DEBUGIT flag in platformio.ini

// i2C params
// Defined in platformio.ini:
// RFID_SDA_PIN=13
// RFID_SCL_PIN=16

#include <Arduino.h>
#include <PowerNodeV11.h>
#include <ACNode.h>
#include <RFID.h>   // NFC version
#include <SIG2.h>
#include <Cache.h>
#include <OptoDebounce.h>
#include <ButtonDebounce.h>
#include <EEPROM.h>
#include <WiFiUdp.h>
#include <NTP.h> // install NTP by Stefan Staub
//
// information about NTP.h, see: https://platformio.org/lib/show/5438/NTP
//

#include "MCP23017IO.h"
#include "PressureSensor.h"
#include ".passwd.h"

/* If using WiFi instead of a fixed ethernet connection, and/or OTA:

Add Passwd.h to the NodeOven/src directoy containing the following information

#pragma once

#define WIFI_NETWORK "YOUR_SSID"
#define WIFI_PASSWD "YOUR_PASSWD"

#define OTA_PASSWD "YOUR_OTA_PASSWD"
*/

// software version
#define SOFTWARE_VERSION "  V0.0.0.1 "

#define MACHINE "argongas"

// See https://mailman.makerspaceleiden.nl/mailman/private/deelnemers/2019-February/019837.html

// Introduced by alex - 2020-01-8



#define SEND_MAIL_MESSAGES_RAW                  (true)  // set to false for encrypted messages (after test)
// Clear EEProm + Cache button
// Press BUT1 on Olimex ESP32 PoE module before (re)boot of node
// keep BUT1 pressed for at least 5 s
// After the release of BUT1 node will restart with empty EEProm and empty cache
#define CLEAR_EEPROM_AND_CACHE_BUTTON           (34)
#define CLEAR_EEPROM_AND_CACHE_BUTTON_PRESSED   (LOW)
#define MAX_WAIT_TIME_BUTTON_PRESSED            (4000)  // in ms

// #define MAX_WAIT_FOR_CARD_TIME                  (60) // in s = 60 seconds
// #define MAX_TIME_BEFORE_WARNING                 (60 * 60 * 4) // in s = 4 hour
// #define MAX_TIME_BEFORE_ALARM                   (60 * 60 * 2) // in s = 2 hour
// for test
#define MAX_WAIT_FOR_CARD_TIME                  (20) // in s = 20 seconds
#define MAX_TIME_BEFORE_WARNING                 (30) // in s = 30 seconds
#define MAX_TIME_BEFORE_ALARM                   (30) // in s = 30 seconds
// end for

#define CHECK_NFC_READER_AVAILABLE_TIME_WINDOW  (10000) // in ms  
#define GPIOPORT_I2C_RECOVER_RELAY              (15)       

#define CHECK_SWITCH1_INPUT_TIME_INTERVAL       (100) // in ms
#define CHECK_PRESSURE_TIME_INTERVAL            (100) // in ms

#define ERROR_LED_INTERVAL                      (500) // in ms

#define OPTO_COUPLER_INPUT1                     (32)
#define OPTO_COUPLER_INPUT2                     (33)  // in this node used as output
#define OPTO_COUPLER_INPUT3                     (36)

#define RED_LED                                 (OPTO_COUPLER_INPUT2)

#define PRESSURESENSOR                          (35)  // analog input
#define INFO_CALIBRATION_BUTTON                 (34)  // this is the same as the CLEAR_EEPROM_AND_CACHE_BUTTON, BUT1 of the ESP32-PoE
                                                      // pressing this button toggles Info / Calibration mode on of off. If on, IP address
                                                      // and calibration information will be logged via MQTT and telnet
// time window for calibration buttons
#define CALIB_WINDOW_TIME                       (5000) // in ms

bool checkCalibButtonsPressed = false;
long int checkCalibTimeOut = 0;
bool showInfoAndCalibration = false;

// Pressure limits, used to check if valve of gasbottle is open or not
#define PRESSURE_VALVE_OPEN                     (2.0) // Pressure if valve of Argon gas bottle is open
#define PRESSURE_VALVE_CLOSED                   (1.0) // If valve is cloded

#define BUTTON_INFO_CALIBRATION_PRESSED         (LOW) // the input level of te GPIO port used for button info and calibrations, if this button is pressed

// pressure sensor
PressureSensor thePressureSensor(PRESSURE_VALVE_OPEN, PRESSURE_VALVE_CLOSED);

// 230VAC optocoupler
OptoDebounce opto1(OPTO_COUPLER_INPUT1); // wired to the 230VAC of the welding equipment, to detect if it is switched on or not

ButtonDebounce buttonInfoCalibration(INFO_CALIBRATION_BUTTON, 150 /* mSeconds */); // buttonInfoCalibration is used to toggle Info / Calibration mode on/off

#ifdef WIFI_NETWORK
ACNode node = ACNode(MACHINE, WIFI_NETWORK, WIFI_PASSWD);
#else
ACNode node = ACNode(MACHINE);
#endif

#define USE_CACHE_FOR_TAGS true
#define USE_NFC_RFID_CARD true

// NTP update window
#define NTP_UPDATE_WINDOW (60000) // in ms
#define CHECK_ARGON_GAS_VALVE_CLOSED_HOUR       (1)

RFID reader = RFID(USE_CACHE_FOR_TAGS, USE_NFC_RFID_CARD); // use tags are stored in cache, to allow access in case the MQTT server is down; also use NFC RFID card

MqttLogStream mqttlogStream = MqttLogStream();
TelnetSerialStream telnetSerialStream = TelnetSerialStream();

#ifdef OTA_PASSWD
OTA ota = OTA(OTA_PASSWD);
#endif

WiFiUDP wifiUDP;
NTP ntp(wifiUDP);

char ntpBootDateTimeStr[64];
unsigned long NTPUpdatedTime = 0;
int previousHour = -1;

char ntpCurrentDateTimeStr[64];
int currentHour;
int currentMinutes;
int currentSecs;
int currentDay;
int currentMonth;
int currentYear;

bool errorLedIsOn = false;
unsigned long errorLedInterval = 0;
bool errorDeelnemersIsActive = false;
bool errorBestuurIsActive = false;
bool panicButtonWasPressed = false;
bool resetButtonWasPressed = false;

// LED aartLed = LED(SYSTEM_LED);    // defaults to the aartLed - otherwise specify a GPIO.

typedef enum {
  BOOTING,                  // starting up
  OUTOFORDER,               // device not functional.
  REBOOT,                   // forcefull reboot
  TRANSIENTERROR,           // hopefully goes away level error
  NOCONN,                   // sort of fairly hopless (though we can cache RFIDs!)
  NOTACTIVE,                // waiting for card.
  CHECKINGCARD,
  CLEARSTATUS,
  APPROVED,
  REJECTED,
  ACTIVENOTAPPROVED,
  SENDWARNINGACTIVENOTAPPROVED,
  WARNINGACTIVENOTAPPROVED,
  SENDALARMACTIVENOTAPPROVED,
  ALARMACTIVENOTAPPROVED,
  ACTIVEAPPROVED,
  SENDWARNINGACTIVEAPPROVED,
  WARNINGACTIVEAPPROVED,
  SENDALARMACTIVEAPPROVED,
  ALARMACTIVEAPPROVED,
} machinestates_t;


#define NEVER (0)

struct {
  const char * label;                   // name of this state
  LED::led_state_t ledState;            // flashing pattern for the aartLED. Zie ook https://wiki.makerspaceleiden.nl/mediawiki/index.php/Powernode_1.1.
  time_t maxTimeInMilliSeconds;         // how long we can stay in this state before we timeout.
  machinestates_t failStateOnTimeout;   // what state we transition to on timeout.
  unsigned long timeInState;
  unsigned long timeoutTransitions;
  unsigned long autoReportCycle;
} state[ALARMACTIVEAPPROVED + 1] =
{
  { "Booting",                           LED::LED_ERROR,                      120 * 1000, REBOOT,                       0 },
  { "Module out of order",               LED::LED_ERROR,                      120 * 1000, REBOOT,                       5 * 60 * 1000 },
  { "Rebooting",                         LED::LED_ERROR,                      120 * 1000, REBOOT,                       0 },
  { "Transient Error",                   LED::LED_ERROR,                        5 * 1000, NOTACTIVE,                    5 * 60 * 1000 },
  { "No network",                        LED::LED_FLASH,                           NEVER, NOCONN,                       0 },
  { "Not active",                        LED::LED_IDLE,                            NEVER, NOTACTIVE,                    0 },
  { "Checking card",                     LED::LED_PENDING,                      5 * 1000, REJECTED,                     0 },
  { "Clear status",                      LED::LED_PENDING,                         NEVER, NOTACTIVE,                    0 },
  { "Approved card",                     LED::LED_PENDING, MAX_WAIT_FOR_CARD_TIME * 1000, CLEARSTATUS,                  0 },
  { "Rejected",                          LED::LED_ERROR,                        5 * 1000, CLEARSTATUS,                  0 },
  { "Active, not approved",              LED::LED_FLASH,   MAX_WAIT_FOR_CARD_TIME * 1000, SENDWARNINGACTIVENOTAPPROVED, 0 },
  { "Send warning active, not approved", LED::LED_ERROR,                           NEVER, WARNINGACTIVENOTAPPROVED,     0 },
  { "Warning active, not approved",      LED::LED_ERROR,    MAX_TIME_BEFORE_ALARM * 1000, SENDALARMACTIVENOTAPPROVED,   0 },
  { "Send alarm active, not approved",   LED::LED_ERROR,                           NEVER, ALARMACTIVENOTAPPROVED,       0 },
  { "Alarm active, not approved",        LED::LED_ERROR,                           NEVER, ALARMACTIVENOTAPPROVED,       0 },
  { "Active and approved",               LED::LED_ON,     MAX_TIME_BEFORE_WARNING * 1000, SENDWARNINGACTIVEAPPROVED,    0 },
  { "Send warning active and approved",  LED::LED_ON,                              NEVER, WARNINGACTIVEAPPROVED,        0 },
  { "Warning active and approved",       LED::LED_ON,       MAX_TIME_BEFORE_ALARM * 1000, SENDALARMACTIVEAPPROVED,      0 },
  { "Send alarm active and approved",    LED::LED_ON,                              NEVER, ALARMACTIVEAPPROVED,          0 },
  { "Alarm active and approved",         LED::LED_ON,                              NEVER, ALARMACTIVEAPPROVED,          0 },
};

unsigned long laststatechange = 0, lastReport = 0;
static machinestates_t laststate = OUTOFORDER;
machinestates_t machinestate = BOOTING;

// to handle onconnect only once (only after reboot)
static bool firstOnConnectTime = true;

char reportStr[128];

unsigned long approvedCards = 0;
unsigned long rejectedCards = 0;

// For storing the local IP address of the node
IPAddress theLocalIPAddress;

unsigned long lastCheckNFCReaderTime = 0;

bool valveIsOpen = false;

bool valveIsOpenError = false;

bool previousWeldingIsOn = false;

bool previousPanicButtonPressed = false;

bool previousResetButtonPressed = false;

bool redLedIsOn = false;

bool nodeWasConnected = false;

void checkClearEEPromAndCacheButtonPressed(void) {
  unsigned long ButtonPressedTime;
  unsigned long currentSecs;
  unsigned long prevSecs;
  bool firstTime = true;

  // check CLEAR_EEPROM_AND_CACHE_BUTTON pressed
  pinMode(CLEAR_EEPROM_AND_CACHE_BUTTON, INPUT);
  // check if button is pressed for at least 3 s
  Log.println("Checking if the button is pressed for clearing EEProm and cache");
  ButtonPressedTime = millis();  
  prevSecs = MAX_WAIT_TIME_BUTTON_PRESSED / 1000;
  Log.print(prevSecs);
  Log.print(" s");
  while (digitalRead(CLEAR_EEPROM_AND_CACHE_BUTTON) == CLEAR_EEPROM_AND_CACHE_BUTTON_PRESSED) {
    if ((millis() - ButtonPressedTime) >= MAX_WAIT_TIME_BUTTON_PRESSED) {
      if (firstTime == true) {
        Log.print("\rPlease release button");
        firstTime = false;
      }
    } else {
      currentSecs = (MAX_WAIT_TIME_BUTTON_PRESSED - millis()) / 1000;
      if ((currentSecs != prevSecs) && (currentSecs >= 0)) {
        Log.print("\r");
        Log.print(currentSecs);
        Log.print(" s");
        prevSecs = currentSecs;
      }
    }
  }
  if (millis() - ButtonPressedTime >= MAX_WAIT_TIME_BUTTON_PRESSED) {
    Log.print("\rButton for clearing EEProm and cache was pressed for more than ");
    Log.print(MAX_WAIT_TIME_BUTTON_PRESSED / 1000);
    Log.println(" s, EEProm and Cache will be cleared!");
    // Clear EEPROM
    EEPROM.begin(1024);
    wipe_eeprom();
    Log.println("EEProm cleared!");
    // Clear cache
    prepareCache(true);
    Log.println("Cache cleared!");
    // wait until button is released, than reboot
    while (digitalRead(CLEAR_EEPROM_AND_CACHE_BUTTON) == CLEAR_EEPROM_AND_CACHE_BUTTON_PRESSED) {
      // do nothing here
    }
    Log.println("Node will be restarted");
    // restart node
    ESP.restart();
  } else {
    Log.println("\rButton was not (or not long enough) pressed to clear EEProm and cache");
  }
}

void setup_GPIO() {
  // for recovery relay I2C
  pinMode(GPIOPORT_I2C_RECOVER_RELAY, OUTPUT);
  digitalWrite(GPIOPORT_I2C_RECOVER_RELAY, 0);
  // for red LED
  pinMode(RED_LED, OUTPUT);
  digitalWrite(RED_LED, LOW);

  // pinMode(OPTO_COUPLER_INPUT1, INPUT);
}

void redLedOn() {
  if (!redLedIsOn) {
    digitalWrite(RED_LED, HIGH);
    redLedIsOn = true;
  }
}

void redLedOff() {
  if (redLedIsOn) {
    digitalWrite(RED_LED, LOW);
    redLedIsOn = false;
  }
}
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
void loop() {
  node.loop();

  now = millis();

  optocoupler_loop();

  checkSignals_Loop();

  thePressureSensor.loop();

  if (showInfoAndCalibration && thePressureSensor.newCalibrationInfoAvailable) {
      Log.println("Compressor Node Info");
      Log.print("Software version :");
      Log.println(SOFTWARE_VERSION);
      theLocalIPAddress = node.localIP();
      Log.print("IP address: ");
      Log.println(theLocalIPAddress.toString());
      thePressureSensor.logInfoCalibration();
      Log.println("");
    }

  if ((now - pressureSampleTime) > 5000) {
    pressureSampleTime = now;
    Serial.printf("Argon gas pressure = %0.5f bar\n\r", thePressureSensor.currentPressure());
  }


  if ((now - NTPUpdatedTime) > NTP_UPDATE_WINDOW) {
    ntp.update();
    NTPUpdatedTime = now;
  }

  if ((now - lastCheckSwitch1) > CHECK_SWITCH1_INPUT_TIME_INTERVAL) {
    loop_MCP23017();
    lastCheckSwitch1 = now;
/*
    currentResetButtonPressed = resetButtonPressed;
    if (currentResetButtonPressed != previousResetButtonPressed) {
      previousResetButtonPressed = resetButtonPressed;
    }
*/    
  }

  if ((now - lastCheckPressure) > CHECK_PRESSURE_TIME_INTERVAL) {
    lastCheckPressure = now;
    currentValveIsOpen = thePressureSensor.valveIsOpen();
    if (currentValveIsOpen != previousValveIsOpen) {
      previousValveIsOpen = currentValveIsOpen;

      getCurrentNTPDateTime();

      if (currentValveIsOpen) {
        valveIsOpen = true;

        Log.printf("%s => Valve is open\n\r", ntpCurrentDateTimeStr);

        if (machinestate == APPROVED) {
          Serial.print("Valve is open and user is already approved!\n\r");
          machinestate = ACTIVEAPPROVED;
        } else {
          Serial.print("Valve is open, while user is not approved yet, use RFID card now!\n\r");
          machinestate = ACTIVENOTAPPROVED;
        }
        signalActiveLampOn();
        signalSafeLampOff();
      } else {
        valveIsOpen = false;

        Log.printf("%s => Valve is closed\n\r", ntpCurrentDateTimeStr);

        machinestate = NOTACTIVE;

        disableAllWarningsAndAlarms();
        Serial.print("Valve is closed\n\r");
        checkDeelnemerErrorIsActive();
        checkBestuurderErrorIsActive();
        resetButtonWasPressed = false;
        blueLedOff();
      }
      valveIsOpenError = false;
    }
  }

  if (USE_NFC_RFID_CARD) {
    if ((now - lastCheckNFCReaderTime) > CHECK_NFC_READER_AVAILABLE_TIME_WINDOW) {
      lastCheckNFCReaderTime = now;
      Serial.print("Check Reader Available\n\r");
      checkNFCReaderAvailable();
    }
  }

  if (laststate != machinestate) {
    Debug.printf("Changed from state <%s> to state <%s>\n",
                 state[laststate].label, state[machinestate].label);

    state[laststate].timeInState += (millis() - laststatechange) / 1000;
    laststate = machinestate;
    laststatechange = millis();
    return;
  }

  warningsAndAlarms_Loop();

  if (state[machinestate].maxTimeInMilliSeconds != NEVER &&
      ((millis() - laststatechange) > state[machinestate].maxTimeInMilliSeconds))
  {
    state[machinestate].timeoutTransitions++;

    laststate = machinestate;
    machinestate = state[machinestate].failStateOnTimeout;

    Log.printf("Time-out; transition from <%s> to <%s>\n",
               state[laststate].label, state[machinestate].label);
    return;
  };

  if (state[machinestate].autoReportCycle && \
      (millis() - laststatechange) > state[machinestate].autoReportCycle && \
      (millis() - lastReport) > state[machinestate].autoReportCycle)
  {
    Log.printf("State: %s now for %lu seconds", state[laststate].label, (millis() - laststatechange) / 1000);
    lastReport = millis();
  };

  switch (machinestate) {
    case REBOOT:
      greenLedOff();
      redLedOff();
      signalActiveLampOff();
      signalSafeLampOff();
      node.delayedReboot();
      break;

    case NOTACTIVE:
    case CHECKINGCARD:
      break;
    case CLEARSTATUS:
      blueLedOff();
      machinestate = NOTACTIVE;
      break;
    case REJECTED:
      rejectedCards++;
      if (valveIsOpen) {
        machinestate = ACTIVENOTAPPROVED;

        getCurrentNTPDateTime();

        Log.printf("%s => RFID tag/card rejected\n\r", ntpCurrentDateTimeStr);    

        // ****** sent error message, valve is open, but card is rejected
        getCurrentNTPDateTime();
        snprintf(mailPayload, sizeof(mailPayload), "{ \"nodename\": \"%s\",  \"subject\": \"Valve argon gas bottle not closed, while RFID card is rejected\", \"DateTime\": \"%s\" }", MACHINE, ntpCurrentDateTimeStr);
        node.send("deelnemers", mailPayload, SEND_MAIL_MESSAGES_RAW);
        node.send("bestuur", mailPayload, SEND_MAIL_MESSAGES_RAW);
        Serial.printf("%s Valve argon gas bottle not closed, while RFID card is rejected\n\r", ntpCurrentDateTimeStr);
        valveIsOpenError = true;
        errorDeelnemersIsActive = true;
        errorBestuurIsActive = true;
      } else {
        machinestate = NOTACTIVE;
      }
      break;
    case ACTIVENOTAPPROVED:
      break;
    case SENDWARNINGACTIVENOTAPPROVED:
        if (valveIsOpen) {
          setNotApprovedWarning();
          // ****** sent error message, valve still open after max time
          getCurrentNTPDateTime();
          snprintf(mailPayload, sizeof(mailPayload), "{ \"nodename\": \"%s\",  \"subject\": \"Valve argon gas still open? While not approved, gas pressure detected for at least %d hours\", \"DateTime\": \"%s\" }", MACHINE, MAX_TIME_BEFORE_WARNING / 3600, ntpCurrentDateTimeStr);
          node.send("deelnemers", mailPayload, SEND_MAIL_MESSAGES_RAW);
          node.send("bestuur", mailPayload, SEND_MAIL_MESSAGES_RAW);
          Serial.printf("%s Valve argon gas still open? While not approved, gas pressure detected for at least %d hours\n\r", ntpCurrentDateTimeStr, MAX_TIME_BEFORE_WARNING / 3600);
          valveIsOpenError = true;
          errorDeelnemersIsActive = true;
          errorBestuurIsActive = true;
          machinestate = WARNINGACTIVENOTAPPROVED;
        } else {
          machinestate = NOTACTIVE;
        }
      break;
    case WARNINGACTIVENOTAPPROVED:
      break;
    case SENDALARMACTIVENOTAPPROVED:
        // ****** sent error message, valve still open after max time
      if (valveIsOpen) {
        setNotApprovedAlarm();
        // ****** sent error message, valve is open, but no card approved yet
        getCurrentNTPDateTime();
        if (panicButtonWasPressed) {
          snprintf(mailPayload, sizeof(mailPayload), "{ \"nodename\": \"%s\",  \"subject\": \"Panic button was pressed? Panic button was pressed while valve is open but no RFID card was seen \", \"DateTime\": \"%s\" }", MACHINE, ntpCurrentDateTimeStr);
        } else {
          snprintf(mailPayload, sizeof(mailPayload), "{ \"nodename\": \"%s\",  \"subject\": \"Valve argon gas bottle not closed? Valve argon gas bottle not closed, but no RFID card seen for at least %d seconds\", \"DateTime\": \"%s\" }", MACHINE, MAX_WAIT_FOR_CARD_TIME, ntpCurrentDateTimeStr);
        }
        node.send("bestuur", mailPayload, SEND_MAIL_MESSAGES_RAW);
        if (panicButtonWasPressed) {
          Serial.printf("%s Panic button was pressed while valve is open but no RFID card was seen\n\r", ntpCurrentDateTimeStr);
        } else {
          Serial.printf("%s Valve argon gas bottle not closed, but no RFID card seen in at least %d seconds\n\r", ntpCurrentDateTimeStr, MAX_WAIT_FOR_CARD_TIME);
        }
        panicButtonWasPressed = false;
        machinestate = WARNINGACTIVENOTAPPROVED;
        valveIsOpenError = true;
        errorBestuurIsActive = true;
        machinestate = ALARMACTIVENOTAPPROVED;
      } else {
        machinestate = NOTACTIVE;
      }
      break;
    case ALARMACTIVENOTAPPROVED:
      break;
    case APPROVED:
      break;
    case ACTIVEAPPROVED:
      break;
    case SENDWARNINGACTIVEAPPROVED:
        if (valveIsOpen) {
          setApprovedWarning();
          // ****** sent error message, valve still open after max time
          getCurrentNTPDateTime();
          snprintf(mailPayload, sizeof(mailPayload), "{ \"nodename\": \"%s\",  \"subject\": \"Valve argon gas still open? Gas pressure detected for at least %d hours\", \"DateTime\": \"%s\" }", MACHINE, MAX_TIME_BEFORE_WARNING / 3600, ntpCurrentDateTimeStr);
          node.send("deelnemers", mailPayload, SEND_MAIL_MESSAGES_RAW);
          Serial.printf("%s Valve argon gas still open? Gas pressure detected for at least %d hours\n\r", ntpCurrentDateTimeStr, MAX_TIME_BEFORE_WARNING / 3600);
          valveIsOpenError = true;
          errorDeelnemersIsActive = true;
          machinestate = WARNINGACTIVEAPPROVED;
        } else {
          machinestate = NOTACTIVE;
        }
      break;
    case WARNINGACTIVEAPPROVED:
      break;
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

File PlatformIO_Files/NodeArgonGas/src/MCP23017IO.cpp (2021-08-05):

#include <Wire.h>
#include "MCP23017IO.h"
#include <Arduino.h>
//#include "RFID.h"

Adafruit_MCP23017 mcp;


#define INPUT_CHANGE_WINDOW     500 // in ms = time input changes are not taking into account
#define FET1_OUTPUT             11
#define FET2_OUTPUT             12
#define RELAY1_OUTPUT           8
#define RELAY2_OUTPUT           9
#define RELAY3_OUTPUT           10
#define SWITCH1_INPUT           0
#define SWITCH2_INPUT           1
#define SWITCH3_INPUT           2

#define PANIC_BUTTON            SWITCH1_INPUT
#define RESET_BUTTON            SWITCH2_INPUT
#define SIGNAL_SAFE_LAMP        RELAY2_OUTPUT
#define SIGNAL_ACTIVE_LAMP      RELAY3_OUTPUT
#define GREEN_LED               FET1_OUTPUT
#define BLUE_LED                SWITCH3_INPUT // for this node used as output
#define BUZZER                  FET2_OUTPUT

// unsigned long lastInputCheck = 0;
// int lastSwitch1Input = 0;

unsigned long lastResetButtonChecked = 0;
bool resetButtonPressed = false;
unsigned long lastPanicButtonChecked = 0;
bool panicButtonPressed = false;
bool signalSafeLampIsOn = false;
bool signalActiveLampIsOn = false;
bool greenLedIsOn = false;
bool blueLedIsOn = false;
bool buzzerIsOn = false;

void setup_MCP23017() {
    Wire.begin(RFID_SDA_PIN, RFID_SCL_PIN, RFID_I2C_FREQ);
    mcp.begin(&Wire);
    mcp.pinMode(RESET_BUTTON, INPUT);
    mcp.pullUp(RESET_BUTTON, HIGH);
    mcp.pinMode(PANIC_BUTTON, INPUT);
    mcp.pullUp(PANIC_BUTTON, HIGH);
    mcp.pinMode(SIGNAL_SAFE_LAMP, OUTPUT);
    mcp.digitalWrite(SIGNAL_SAFE_LAMP, 0);
    mcp.pinMode(SIGNAL_ACTIVE_LAMP, OUTPUT);
    mcp.digitalWrite(SIGNAL_ACTIVE_LAMP, 0);
    mcp.pinMode(GREEN_LED, OUTPUT);
    mcp.digitalWrite(GREEN_LED, 0);
    mcp.pinMode(BLUE_LED, OUTPUT);
    mcp.digitalWrite(BLUE_LED, 0);
    mcp.pinMode(BUZZER, OUTPUT);
    mcp.digitalWrite(BUZZER, 0);
}

void signalSafeLampOn() {
    if (!signalSafeLampIsOn) {
        mcp.digitalWrite(SIGNAL_SAFE_LAMP, 1);
        signalSafeLampIsOn = true;
    }
}

void signalSafeLampOff() {
    if (signalSafeLampIsOn) {
        mcp.digitalWrite(SIGNAL_SAFE_LAMP, 0);
        signalSafeLampIsOn = false;
    }
}

void signalActiveLampOn() {
    if (!signalActiveLampIsOn) {
        mcp.digitalWrite(SIGNAL_ACTIVE_LAMP, 1);
        signalActiveLampIsOn = true;
    }
}

void signalActiveLampOff() {
    if (signalActiveLampIsOn) {
        mcp.digitalWrite(SIGNAL_ACTIVE_LAMP, 0);
        signalActiveLampIsOn = false;
    }
}

void greenLedOn() {
    if (!greenLedIsOn) {
        mcp.digitalWrite(GREEN_LED, 1);
        greenLedIsOn = true;
    }
}

void greenLedOff() {
    if (greenLedIsOn) {
        mcp.digitalWrite(GREEN_LED, 0);
        greenLedIsOn = false;
    }
}

void blueLedOn() {
    if (!blueLedIsOn) {
        mcp.digitalWrite(BLUE_LED, 1);
        blueLedIsOn = true;
    }
}

void blueLedOff() {
    if (blueLedIsOn) {
        mcp.digitalWrite(BLUE_LED, 0);
        blueLedIsOn = false;
    }
}

void buzzerOn() {
    if (!buzzerIsOn) {
        mcp.digitalWrite(BUZZER, 1);
        buzzerIsOn = true;
    }
}

void buzzerOff() {
    if (buzzerIsOn) {
        mcp.digitalWrite(BUZZER, 0);
        buzzerIsOn = false;
    }
}

void loop_MCP23017() {
    unsigned long now = millis();
    bool currentResetButtonPressed = (mcp.digitalRead(RESET_BUTTON) == 0);
    if ((currentResetButtonPressed != resetButtonPressed) && ((now - lastResetButtonChecked) > INPUT_CHANGE_WINDOW)) {
        lastResetButtonChecked = now;
        resetButtonPressed = currentResetButtonPressed;
        if (resetButtonPressed) {
            Serial.print("Reset button pressed\n\r");
        } else {
            Serial.print("Reset button released\n\r");
        }
    }

    now = millis();
    bool currentPanicButtonPressed = (mcp.digitalRead(PANIC_BUTTON) == 0);
    if ((currentPanicButtonPressed != panicButtonPressed) && ((now - lastPanicButtonChecked) > INPUT_CHANGE_WINDOW)) {
        lastPanicButtonChecked = now;
        panicButtonPressed = currentPanicButtonPressed;
        if (panicButtonPressed) {
            Serial.print("Panic button pressed\n\r");
        } else {
            Serial.print("Panic button released\n\r");
        }
    }

}
